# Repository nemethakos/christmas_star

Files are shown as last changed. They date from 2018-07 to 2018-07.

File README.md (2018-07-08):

# Christmas Star
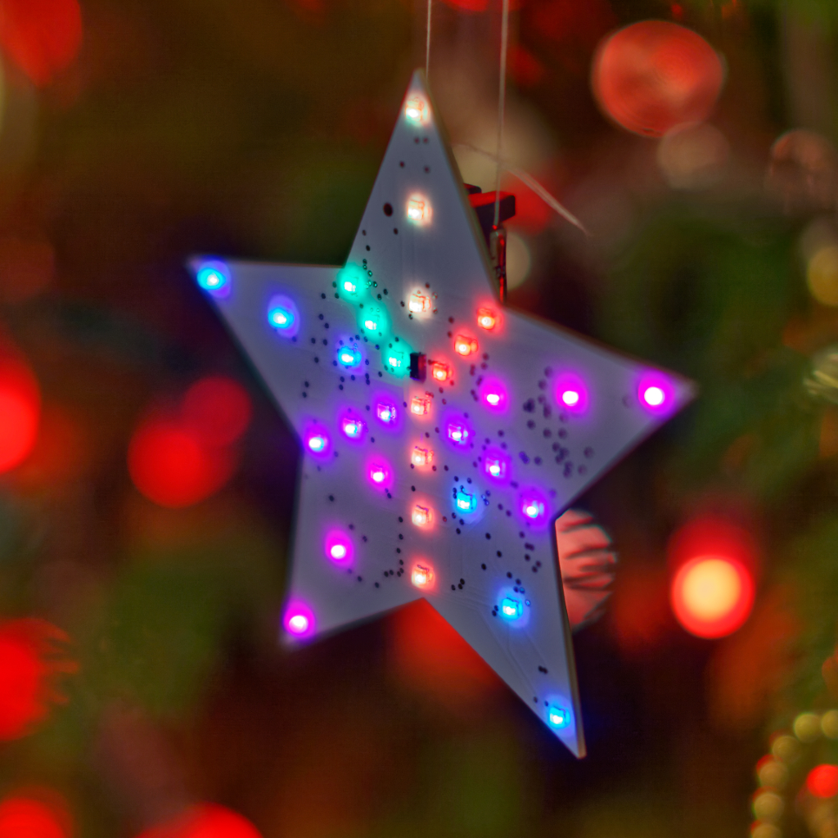
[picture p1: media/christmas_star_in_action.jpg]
Christmas Star in Action

Christmas Star is a Christmas ornament to be hanged onto a Christmas tree. 

It runs on a single AA Battery (Lithium, NiMh or Alkaline), has 31 APA102-2020 RGB LEDs driven by an ATMEGA 328P running on Arduino core. 
Gesture control by Avago APDS-9960 Gesture and Light sensor (sleep/wake up, next/previous effect).

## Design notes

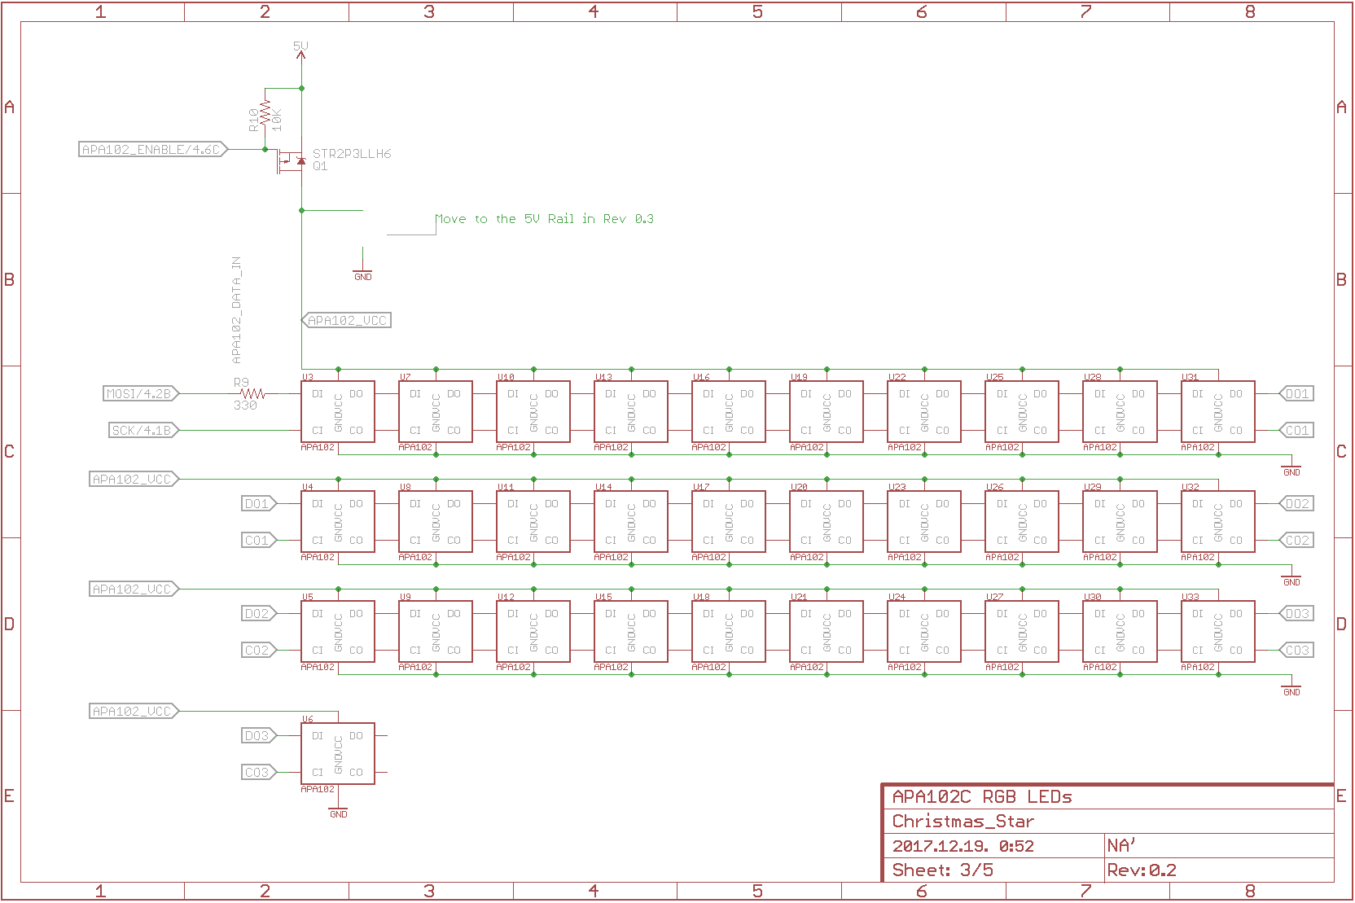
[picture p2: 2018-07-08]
media/sch3.png

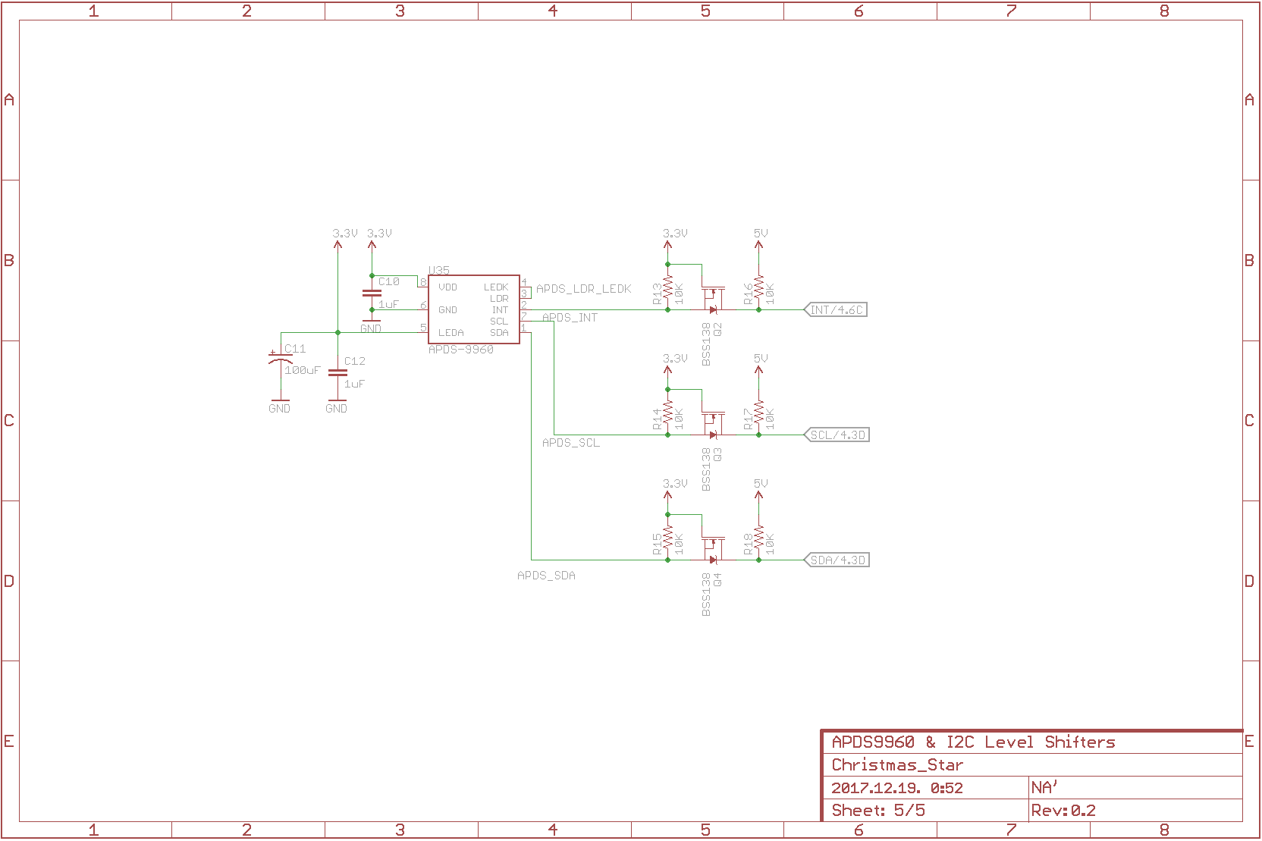
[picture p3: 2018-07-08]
media/sch5.png

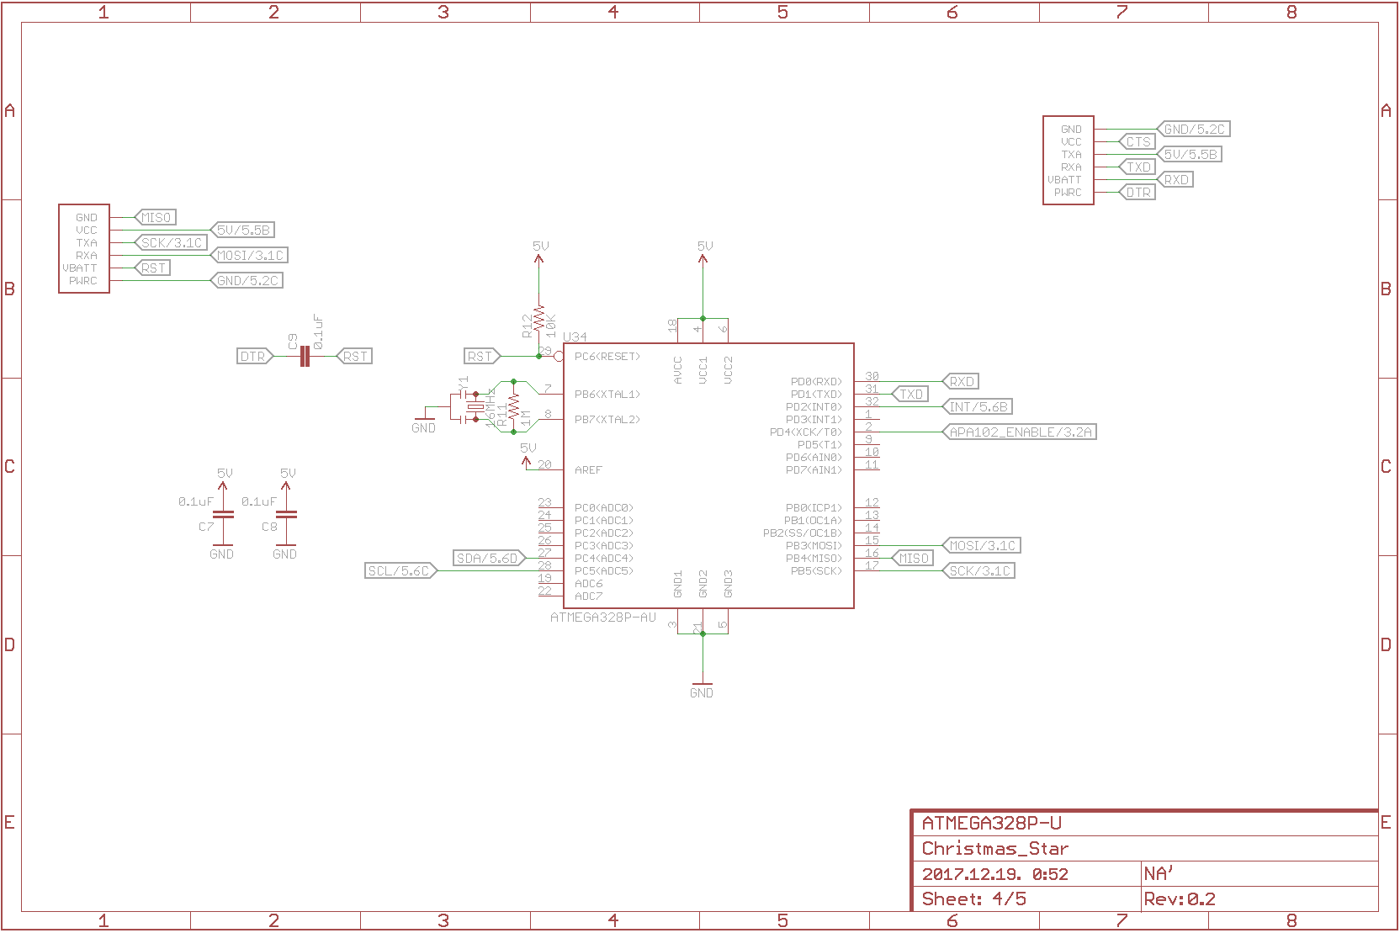
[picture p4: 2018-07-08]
media/sch4.png

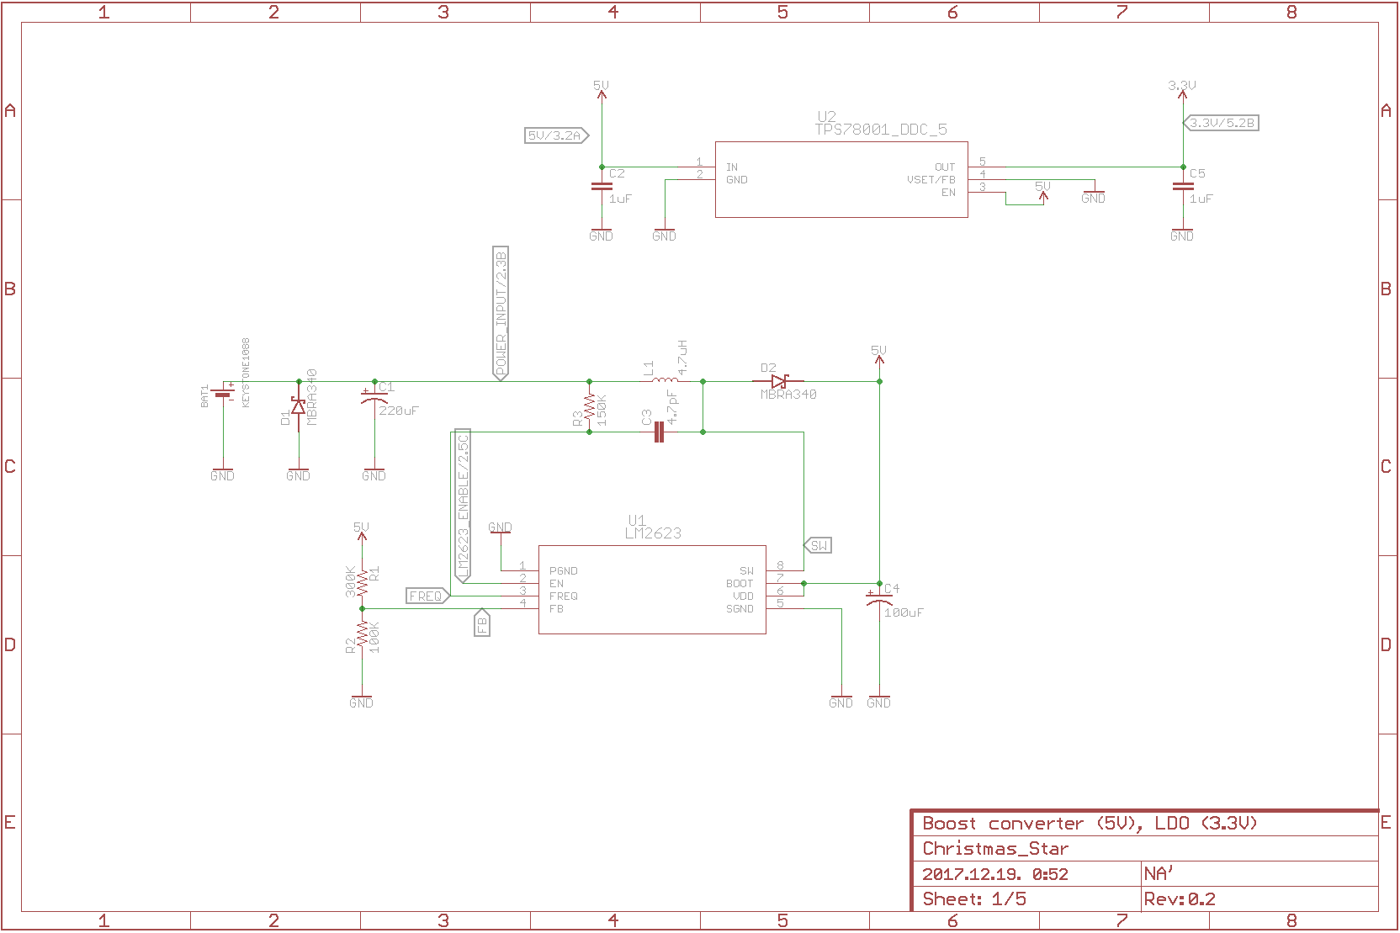
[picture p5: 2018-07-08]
media/sch1.png

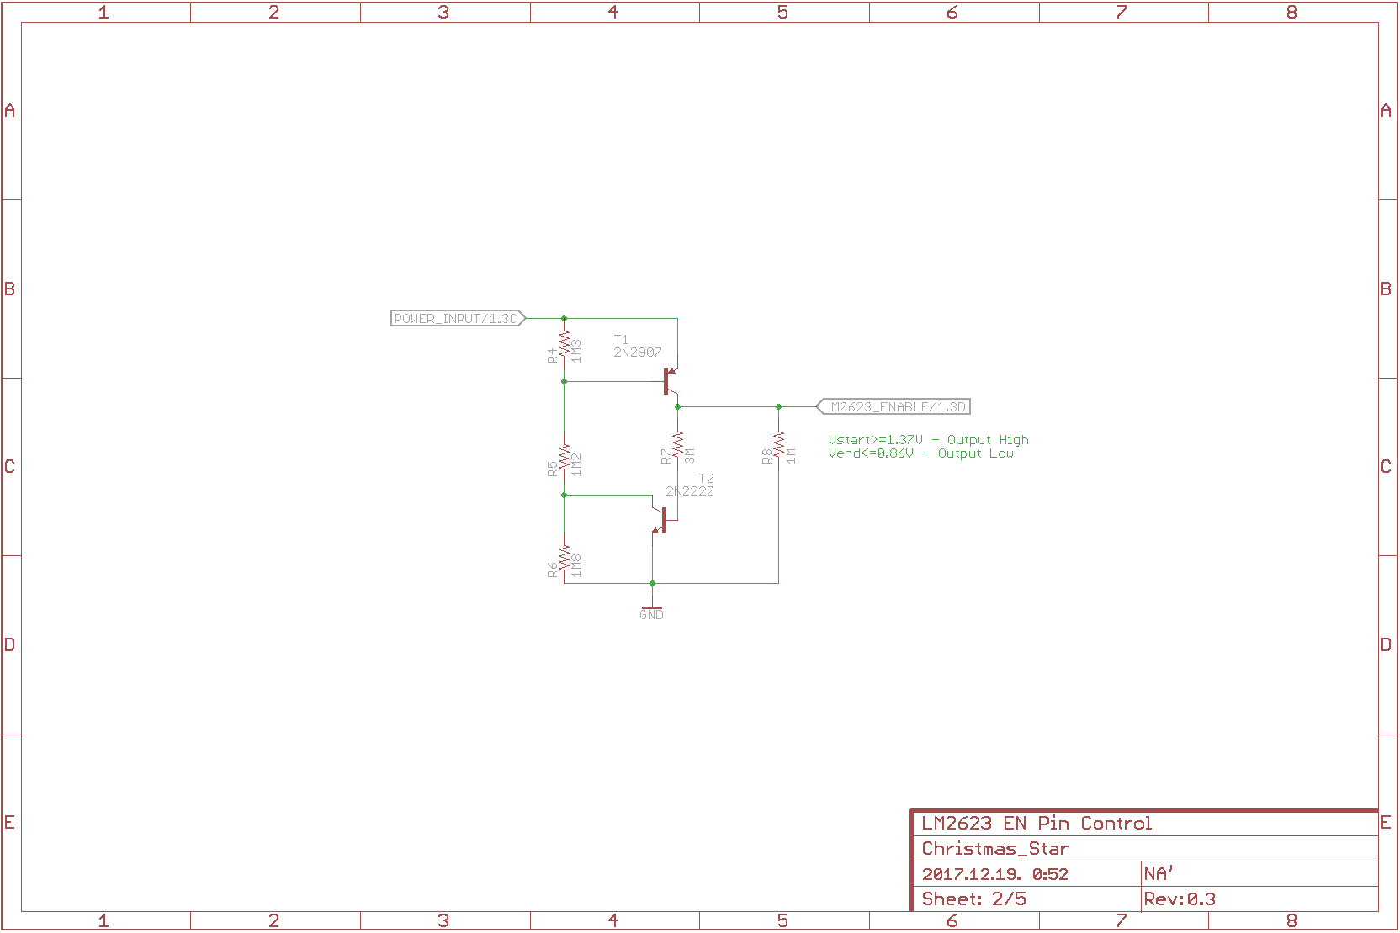
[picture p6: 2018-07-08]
media/sch2.png

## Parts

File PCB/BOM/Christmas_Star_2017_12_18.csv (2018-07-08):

Qty | Value | Device | Package | Parts | Description
3 | 0.1uF | CAP0603-CAP | 0603-CAP | C7, C8, C9 | Capacitor
1 | 1000uF | CPOL-USD/7343-31W | D/7343-31W | C6 | POLARIZED CAPACITOR, American symbol
1 | 100K | RESISTOR0603-RES | 0603-RES | R2 | Resistor
2 | 100uF | CAP_POL1206-KIT | EIA3216-KIT | C4, C11 | Capacitor Polarized
8 | 10K | RESISTOR0603-RES | 0603-RES | R10, R12, R13, R14, R15, R16, R17, R18 | Resistor
1 | 150K | RESISTOR0603-RES | 0603-RES | R3 | Resistor
1 | 16MHz | RESONATOR-16MHZSMD_3.2X1.3 | RESONATOR-SMD-3.2X1.3 | Y1 | 16MHz Resonator
2 | 1M | RESISTOR0603-RES | 0603-RES | R8, R11 | Resistor
1 | 1M2 | RESISTOR0603-RES | 0603-RES | R5 | Resistor
1 | 1M3 | RESISTOR0603-RES | 0603-RES | R4 | Resistor
1 | 1M8 | RESISTOR0603-RES | 0603-RES | R6 | Resistor
4 | 1uF | CAP0603-CAP | 0603-CAP | C2, C5, C10, C12 | Capacitor
1 | 220uF | CAP_POL3528-KIT | EIA3528-KIT | C1 | Capacitor Polarized
1 | 2N2222 | MMBT2222ALT1-NPN-SOT23-BEC | SOT23-BEC | T2 | NPN Transistror
1 | 2N2907 | MMBT2907ALT1-PNP-SOT23-BEC | SOT23-BEC | T1 | PNP Transistror
1 | 300K | RESISTOR0603-RES | 0603-RES | R1 | Resistor
1 | 330 | RESISTOR0603-RES | 0603-RES | R9 | Resistor
1 | 3M | RESISTOR0603-RES | 0603-RES | R7 | Resistor
1 | 4.7pF | CAP0603-CAP | 0603-CAP | C3 | Capacitor
1 | 4.7uH | INDUCTOR | LTF5022 | L1 | LTF5022 Footprint
31 | APA102 | APA1022020 | APA102_2020 | U3, U4, U5, U6, U7, U8, U9, U10, U11, U12, U13, U14, U15, U16, U17, U18, U19, U20, U21, U22, U23, U24, U25, U26, U27, U28, U29, U30, U31, U32, U33 | APA102C 5050 RGB LED
1 | APDS-9960 | APDS-9960 | APDS-9960 | U35 | Avago APDS-9960 Digital Proximity, Ambient Light, RGB, and Gesture Sensor.
1 | ATMEGA328P-AU | ATMEGA328P-AU | TQFP32 | U34 | Atmel 32-pin 8-bit microcontroller
3 | BSS138 | MOSFET-NCH-BSS138 | SOT23-3 | Q2, Q3, Q4 | N-channel MOSFETs
2 | GP-635TSMD | GP-635TSMD | GP-635T | ICSP, SERIAL | Footprint and symbol for a generic 6-pin JST GPS module connector.
1 | KEYSTONE1088 | KEYSTONE1088 | KEYSTONE1088 | BAT1
1 | LM2623_DGK_8 | LM2623_DGK_8 | MUA08A | U1
2 | MBRA340 | SS12 | DIOM4427X270N | D1, D2 | SS12 Series 500 mV 1 A 20 V Max Reverse Voltage Schottky Rectifier - DO-214AC
1 | STR2P3LLH6 | MOSFET_PCH-IRLML2244 | SOT23-3 | Q1 | P-channel MOSFETs
1 | TPS78001_DDC_5 | TPS78001_DDC_5 | DDC5 | U2

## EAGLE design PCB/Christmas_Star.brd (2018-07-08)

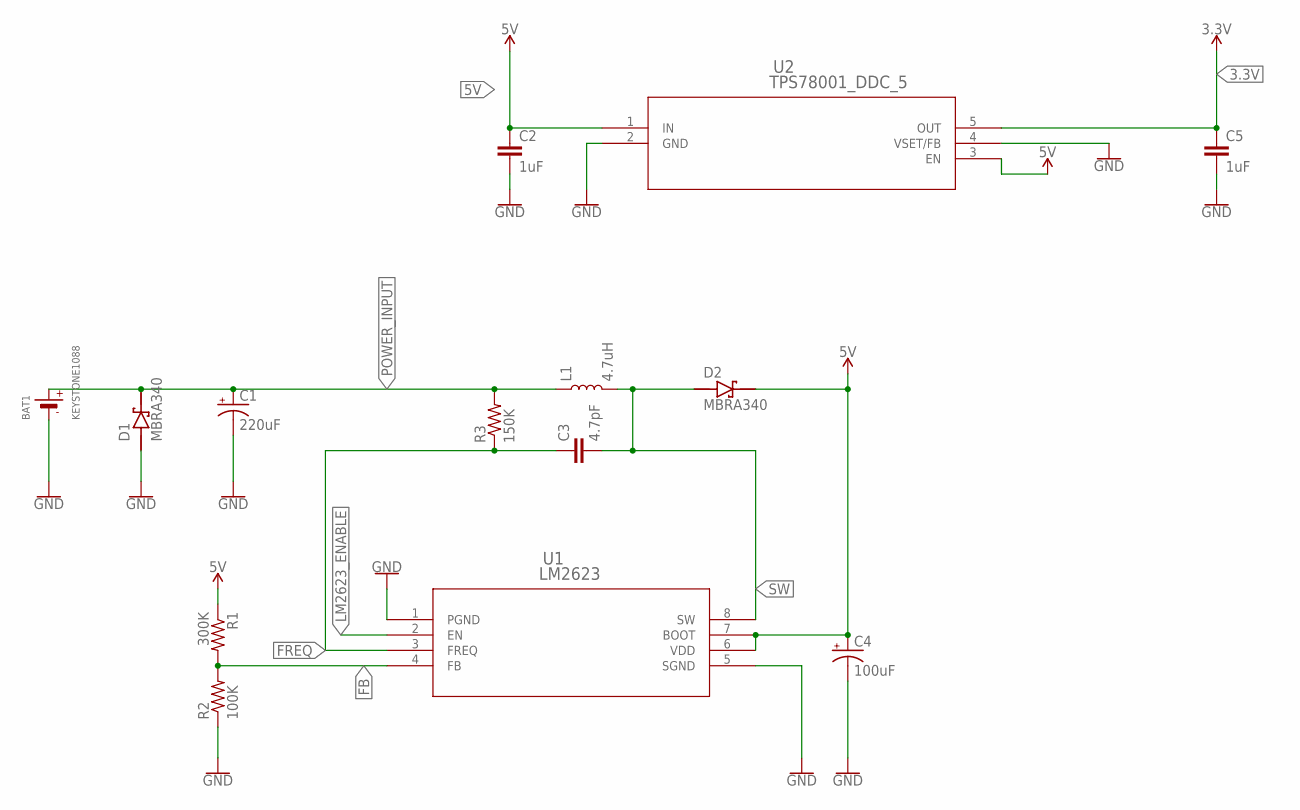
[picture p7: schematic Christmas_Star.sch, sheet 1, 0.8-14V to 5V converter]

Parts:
BAT1: KEYSTONE1088
C1: 220uF; EIA3528-KIT
C2, C5: 1uF; 0603-CAP
C3: 4.7pF; 0603-CAP
C4: 100uF; EIA3216-KIT
D1, D2: MBRA340; DIOM4427X270N
L1: 4.7uH; LTF5022
R1: 300K; 0603-RES
R2: 100K; 0603-RES
R3: 150K; 0603-RES
U1: LM2623; MUA08A
U2: TPS78001_DDC_5; DDC5

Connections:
3.3V: C5.1, U2.5 (OUT); also elsewhere on the board
5V: C2.1, C4.A (+), D2.C, R1.1, U1.6 (VDD), U1.7 (BOOT), U2.1 (IN), U2.3 (EN); also elsewhere on the board
FB: R1.2, R2.2, U1.4 (FB)
FREQ: C3.1, R3.1, U1.3 (FREQ)
GND: BAT1.-, C1.C (-), C2.2, C4.C (-), C5.2, D1.A, R2.1, U1.1 (PGND), U1.5 (SGND), U2.2 (GND), U2.4 (VSET/FB); also elsewhere on the board
LM2623_ENABLE: U1.2 (EN); also elsewhere on the board
POWER_INPUT: BAT1.+, C1.A (+), D1.C, L1.P$1 (1), R3.2; also elsewhere on the board
SW: C3.2, D2.A, L1.P$2 (2), U1.8 (SW)

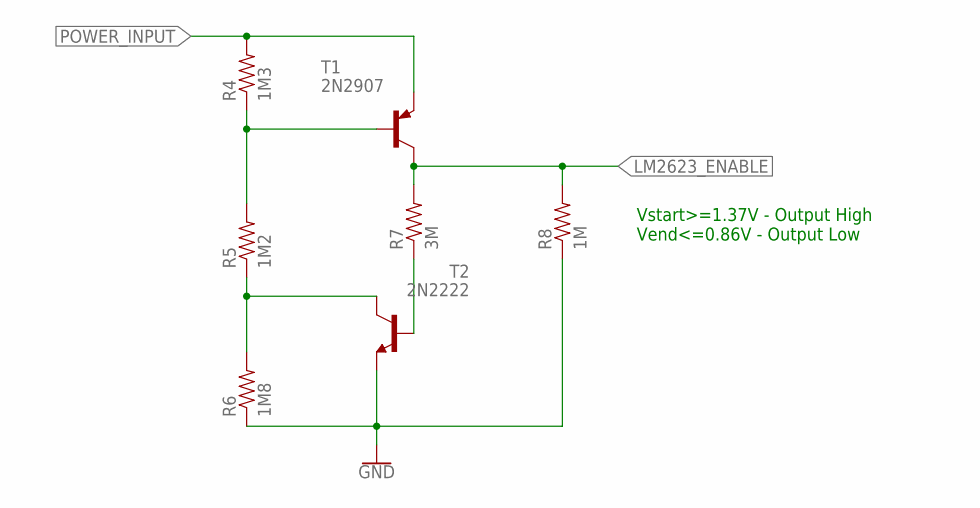
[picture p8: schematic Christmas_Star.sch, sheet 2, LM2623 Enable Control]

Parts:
R4: 1M3; 0603-RES
R5: 1M2; 0603-RES
R6: 1M8; 0603-RES
R7: 3M; 0603-RES
R8: 1M; 0603-RES
T1: 2N2907; SOT23-BEC
T2: 2N2222; SOT23-BEC

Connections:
GND: R6.1, R8.1, T2.E; also elsewhere on the board
LM2623_ENABLE: R7.2, R8.2, T1.C; also elsewhere on the board
unnamed: R4.1, R5.2, T1.B
unnamed: R5.1, R6.2, T2.C
unnamed: R7.1, T2.B
POWER_INPUT: R4.2, T1.E; also elsewhere on the board

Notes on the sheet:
Vstart>=1.37V - Output High Vend<=0.86V - Output Low

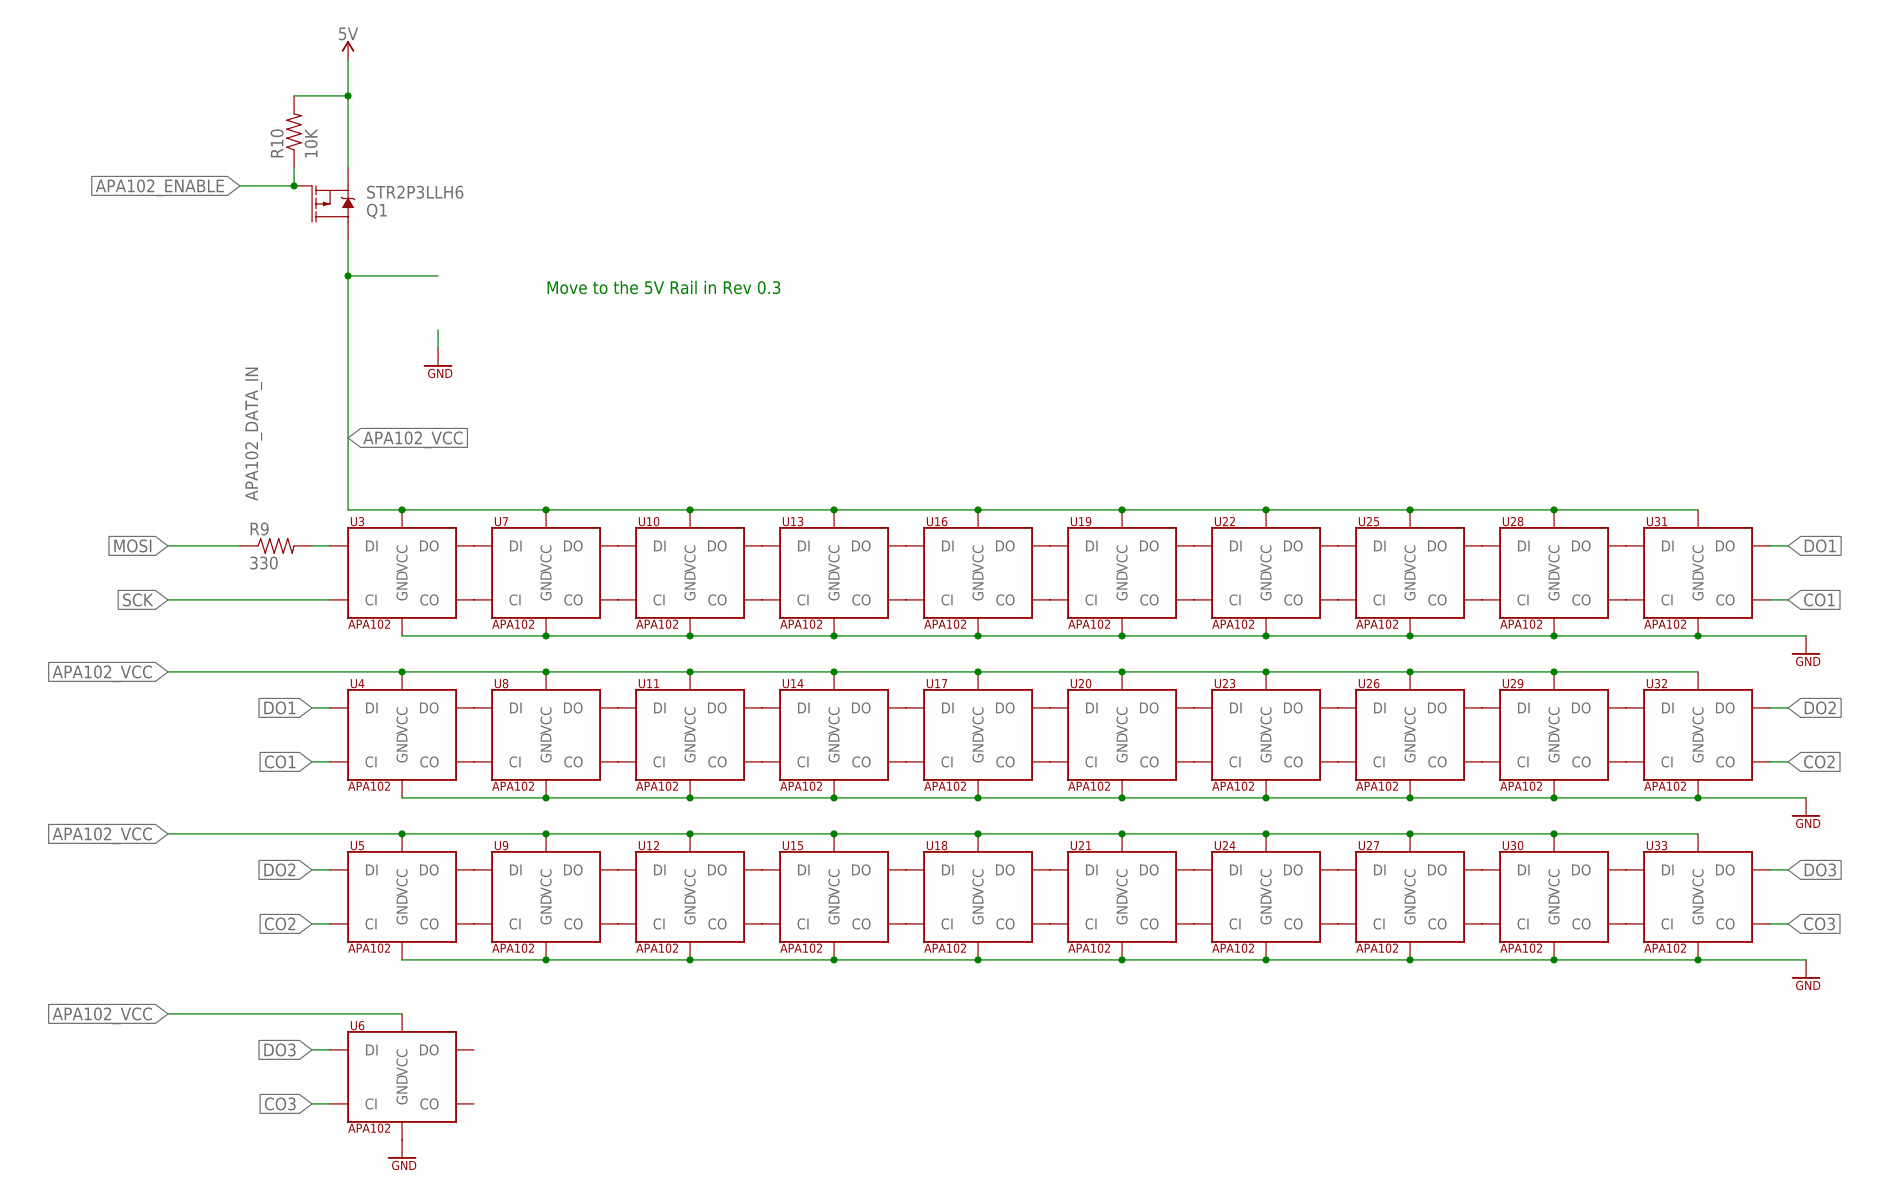
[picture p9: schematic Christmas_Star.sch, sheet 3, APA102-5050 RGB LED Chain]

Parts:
Q1: STR2P3LLH6; SOT23-3
R9: 330; 0603-RES
R10: 10K; 0603-RES
U3, U4, U5, U6, U7, U8, U9, U10, U11, U12, U13, U14, U15, U16, U17, U18, U19, U20, U21, U22, U23, U24, U25, U26, U27, U28, U29, U30, U31, U32, U33: APA102; APA102_2020

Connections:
5V: Q1.2 (S), R10.2; also elsewhere on the board
APA102_DATA_IN: R9.2, U3.D_IN (DI)
APA102_ENABLE: Q1.1 (G), R10.1; also elsewhere on the board
APA102_VCC: Q1.3 (D), U3.VCC, U4.VCC, U5.VCC, U6.VCC, U7.VCC, U8.VCC, U9.VCC, U10.VCC, U11.VCC, U12.VCC, U13.VCC, U14.VCC, U15.VCC, U16.VCC, U17.VCC, U18.VCC, U19.VCC, U20.VCC, U21.VCC, U22.VCC, U23.VCC, U24.VCC, U25.VCC, U26.VCC, U27.VCC, U28.VCC, U29.VCC, U30.VCC, U31.VCC, U32.VCC, U33.VCC
CO1: U4.C_IN (CI), U31.CL_OUT (CO)
CO2: U5.C_IN (CI), U32.CL_OUT (CO)
CO3: U6.C_IN (CI), U33.CL_OUT (CO)
DO1: U4.D_IN (DI), U31.D_OUT (DO)
DO2: U5.D_IN (DI), U32.D_OUT (DO)
DO3: U6.D_IN (DI), U33.D_OUT (DO)
GND: U3.GND, U4.GND, U5.GND, U6.GND, U7.GND, U8.GND, U9.GND, U10.GND, U11.GND, U12.GND, U13.GND, U14.GND, U15.GND, U16.GND, U17.GND, U18.GND, U19.GND, U20.GND, U21.GND, U22.GND, U23.GND, U24.GND, U25.GND, U26.GND, U27.GND, U28.GND, U29.GND, U30.GND, U31.GND, U32.GND, U33.GND; also elsewhere on the board
MOSI: R9.1; also elsewhere on the board
unnamed: U3.D_OUT (DO), U7.D_IN (DI)
unnamed: U3.CL_OUT (CO), U7.C_IN (CI)
unnamed: U7.D_OUT (DO), U10.D_IN (DI)
unnamed: U7.CL_OUT (CO), U10.C_IN (CI)
unnamed: U10.D_OUT (DO), U13.D_IN (DI)
unnamed: U10.CL_OUT (CO), U13.C_IN (CI)
unnamed: U13.D_OUT (DO), U16.D_IN (DI)
unnamed: U13.CL_OUT (CO), U16.C_IN (CI)
unnamed: U16.D_OUT (DO), U19.D_IN (DI)
unnamed: U16.CL_OUT (CO), U19.C_IN (CI)
unnamed: U19.D_OUT (DO), U22.D_IN (DI)
unnamed: U19.CL_OUT (CO), U22.C_IN (CI)
unnamed: U22.D_OUT (DO), U25.D_IN (DI)
unnamed: U22.CL_OUT (CO), U25.C_IN (CI)
unnamed: U25.D_OUT (DO), U28.D_IN (DI)
unnamed: U25.CL_OUT (CO), U28.C_IN (CI)
unnamed: U28.D_OUT (DO), U31.D_IN (DI)
unnamed: U28.CL_OUT (CO), U31.C_IN (CI)
unnamed: U4.D_OUT (DO), U8.D_IN (DI)
unnamed: U4.CL_OUT (CO), U8.C_IN (CI)
unnamed: U8.D_OUT (DO), U11.D_IN (DI)
unnamed: U8.CL_OUT (CO), U11.C_IN (CI)
unnamed: U11.D_OUT (DO), U14.D_IN (DI)
unnamed: U11.CL_OUT (CO), U14.C_IN (CI)
unnamed: U14.D_OUT (DO), U17.D_IN (DI)
unnamed: U14.CL_OUT (CO), U17.C_IN (CI)
unnamed: U17.D_OUT (DO), U20.D_IN (DI)
unnamed: U17.CL_OUT (CO), U20.C_IN (CI)
unnamed: U20.D_OUT (DO), U23.D_IN (DI)
unnamed: U20.CL_OUT (CO), U23.C_IN (CI)
unnamed: U23.D_OUT (DO), U26.D_IN (DI)
unnamed: U23.CL_OUT (CO), U26.C_IN (CI)
unnamed: U26.D_OUT (DO), U29.D_IN (DI)
unnamed: U26.CL_OUT (CO), U29.C_IN (CI)
unnamed: U29.D_OUT (DO), U32.D_IN (DI)
unnamed: U29.CL_OUT (CO), U32.C_IN (CI)
unnamed: U5.D_OUT (DO), U9.D_IN (DI)
unnamed: U5.CL_OUT (CO), U9.C_IN (CI)
unnamed: U9.D_OUT (DO), U12.D_IN (DI)
unnamed: U9.CL_OUT (CO), U12.C_IN (CI)
unnamed: U12.D_OUT (DO), U15.D_IN (DI)
unnamed: U12.CL_OUT (CO), U15.C_IN (CI)
unnamed: U15.D_OUT (DO), U18.D_IN (DI)
unnamed: U15.CL_OUT (CO), U18.C_IN (CI)
unnamed: U18.D_OUT (DO), U21.D_IN (DI)
unnamed: U18.CL_OUT (CO), U21.C_IN (CI)
unnamed: U21.D_OUT (DO), U24.D_IN (DI)
unnamed: U21.CL_OUT (CO), U24.C_IN (CI)
unnamed: U24.D_OUT (DO), U27.D_IN (DI)
unnamed: U24.CL_OUT (CO), U27.C_IN (CI)
unnamed: U27.D_OUT (DO), U30.D_IN (DI)
unnamed: U27.CL_OUT (CO), U30.C_IN (CI)
unnamed: U30.D_OUT (DO), U33.D_IN (DI)
unnamed: U30.CL_OUT (CO), U33.C_IN (CI)
SCK: U3.C_IN (CI); also elsewhere on the board

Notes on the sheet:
Move to the 5V Rail in Rev 0.3

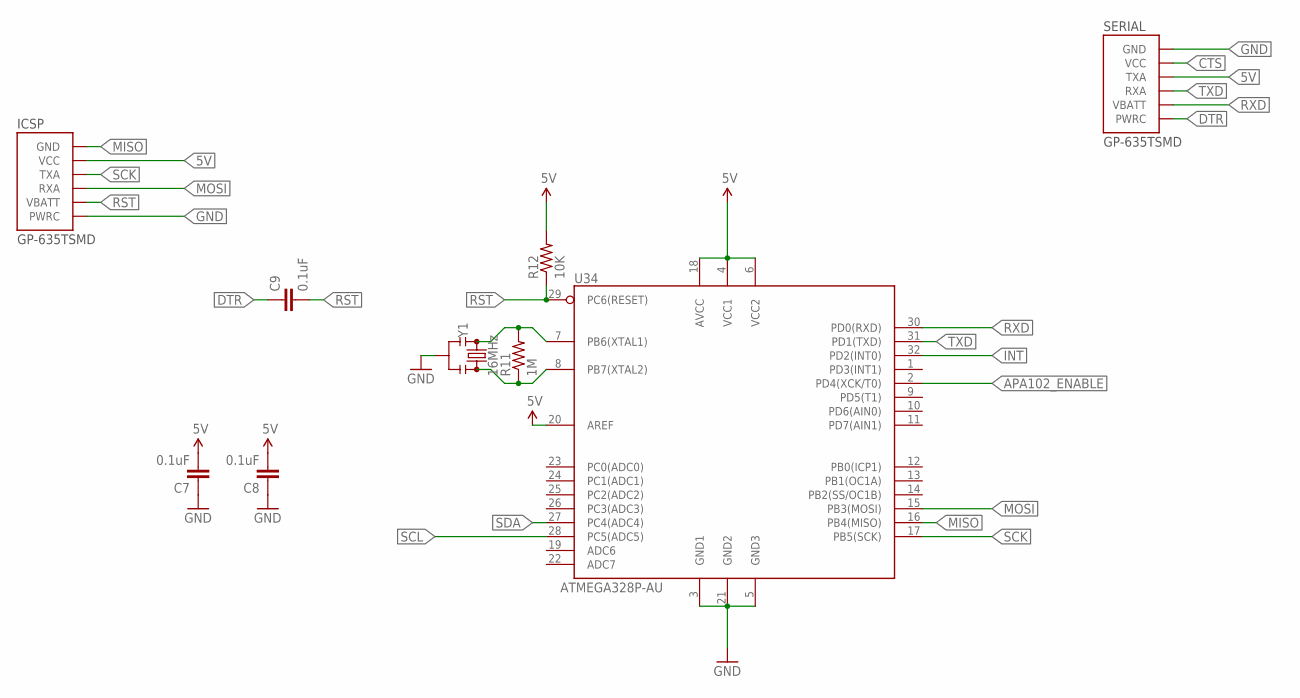
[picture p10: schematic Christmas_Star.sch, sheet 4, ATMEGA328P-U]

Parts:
C7, C8, C9: 0.1uF; 0603-CAP
ICSP: GP-635TSMD; GP-635T
R11: 1M; 0603-RES
R12: 10K; 0603-RES
SERIAL: GP-635TSMD; GP-635T
U34: ATMEGA328P-AU; TQFP32
Y1: 16MHz; RESONATOR-SMD-3.2X1.3

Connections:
5V: C7.2, C8.2, ICSP.2 (VCC), R12.2, SERIAL.3 (TXA), U34.4 (VCC1), U34.6 (VCC2), U34.18 (AVCC), U34.20 (AREF); also elsewhere on the board
APA102_ENABLE: U34.2 (PD4(XCK/T0)); also elsewhere on the board
CTS: SERIAL.2 (VCC)
DTR: C9.1, SERIAL.6 (PWRC)
GND: C7.1, C8.1, ICSP.6 (PWRC), SERIAL.1 (GND), U34.3 (GND1), U34.5 (GND3), U34.21 (GND2), Y1.2; also elsewhere on the board
INT: U34.32 (PD2(INT0)); also elsewhere on the board
MISO: ICSP.1 (GND), U34.16 (PB4(MISO))
MOSI: ICSP.4 (RXA), U34.15 (PB3(MOSI)); also elsewhere on the board
unnamed: R11.2, U34.7 (PB6(XTAL1)), Y1.1
unnamed: R11.1, U34.8 (PB7(XTAL2)), Y1.3
RST: C9.2, ICSP.5 (VBATT), R12.1, U34.29 (PC6(RESET))
RXD: SERIAL.5 (VBATT), U34.30 (PD0(RXD))
SCK: ICSP.3 (TXA), U34.17 (PB5(SCK)); also elsewhere on the board
SCL: U34.28 (PC5(ADC5)); also elsewhere on the board
SDA: U34.27 (PC4(ADC4)); also elsewhere on the board
TXD: SERIAL.4 (RXA), U34.31 (PD1(TXD))

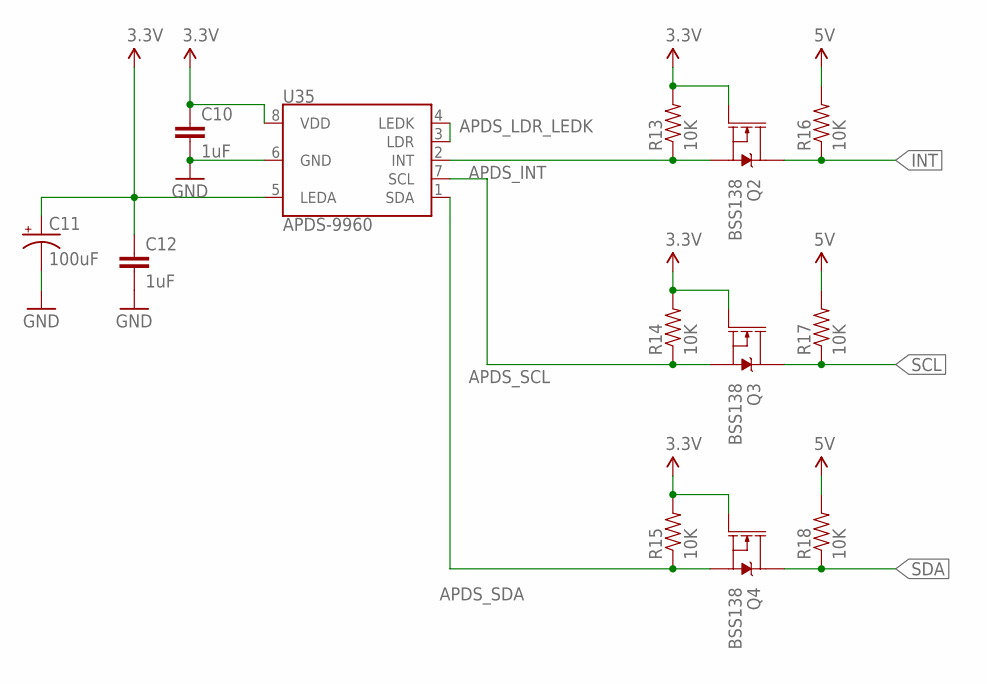
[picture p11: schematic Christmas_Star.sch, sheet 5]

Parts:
C10, C12: 1uF; 0603-CAP
C11: 100uF; EIA3216-KIT
Q2, Q3, Q4: BSS138; SOT23-3
R13, R14, R15, R16, R17, R18: 10K; 0603-RES
U35: APDS-9960

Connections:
3.3V: C10.1, C11.A (+), C12.1, Q2.1 (G), Q3.1 (G), Q4.1 (G), R13.2, R14.2, R15.2, U35.5 (LEDA), U35.8 (VDD); also elsewhere on the board
5V: R16.2, R17.2, R18.2; also elsewhere on the board
APDS_INT: Q2.2 (S), R13.1, U35.2 (INT)
APDS_LDR_LEDK: U35.3 (LDR), U35.4 (LEDK)
APDS_SCL: Q3.2 (S), R14.1, U35.7 (SCL)
APDS_SDA: Q4.2 (S), R15.1, U35.1 (SDA)
GND: C10.2, C11.C (-), C12.2, U35.6 (GND); also elsewhere on the board
INT: Q2.3 (D), R16.1; also elsewhere on the board
SCL: Q3.3 (D), R17.1; also elsewhere on the board
SDA: Q4.3 (D), R18.1; also elsewhere on the board

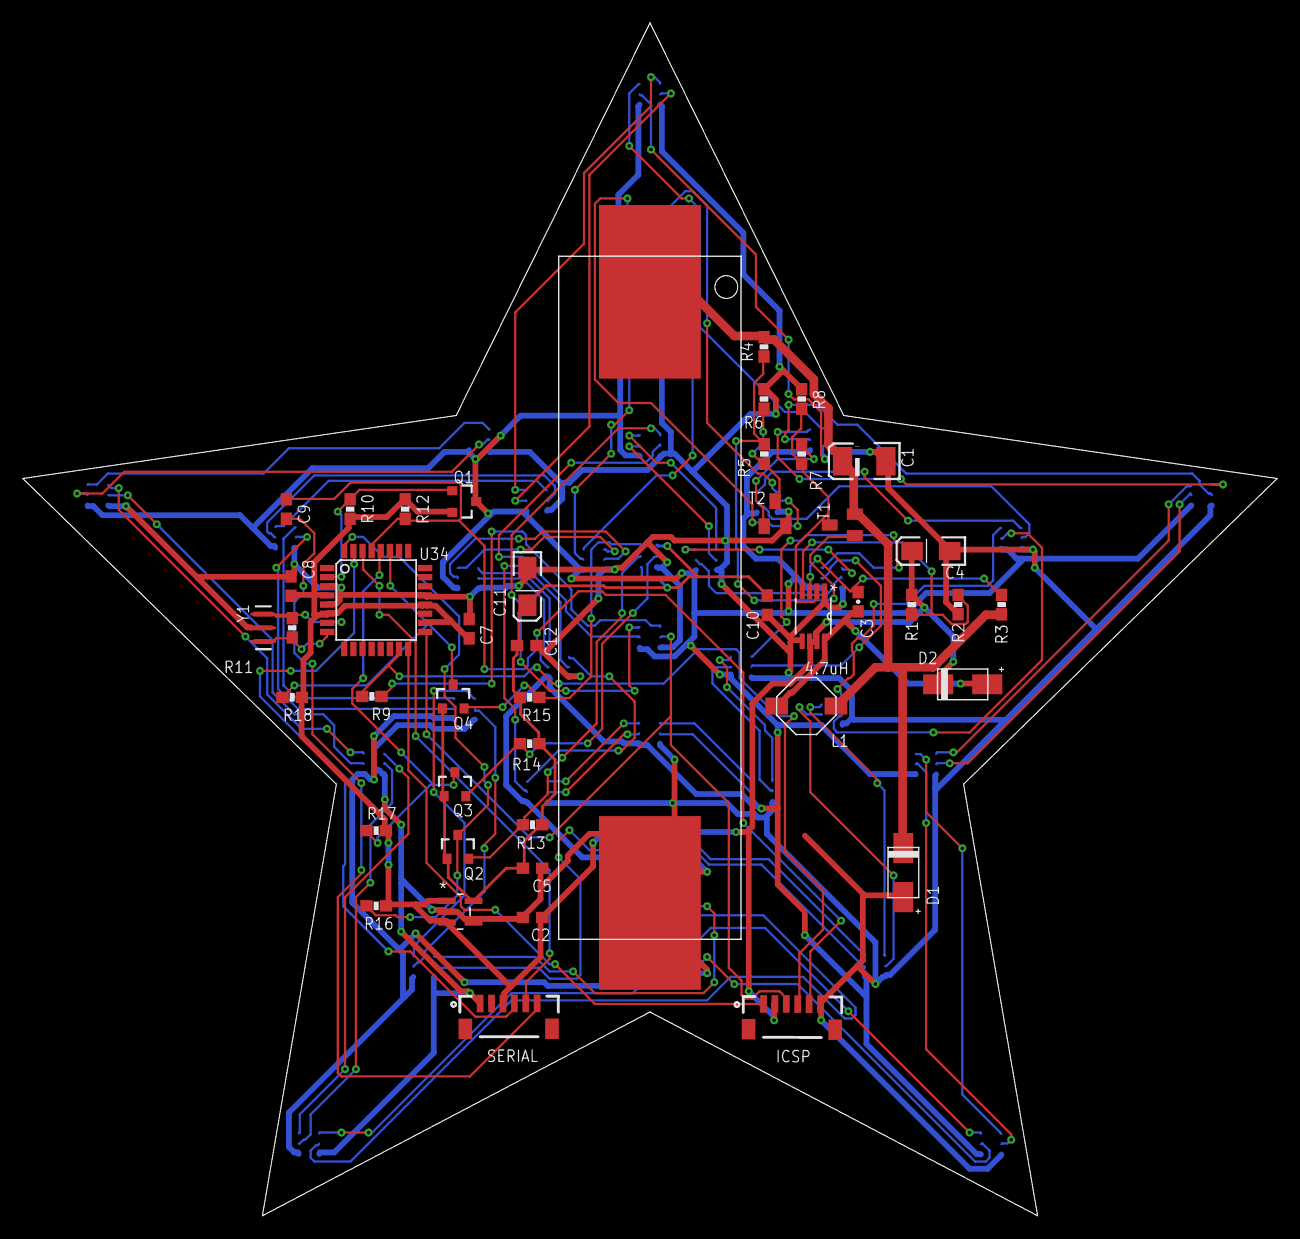
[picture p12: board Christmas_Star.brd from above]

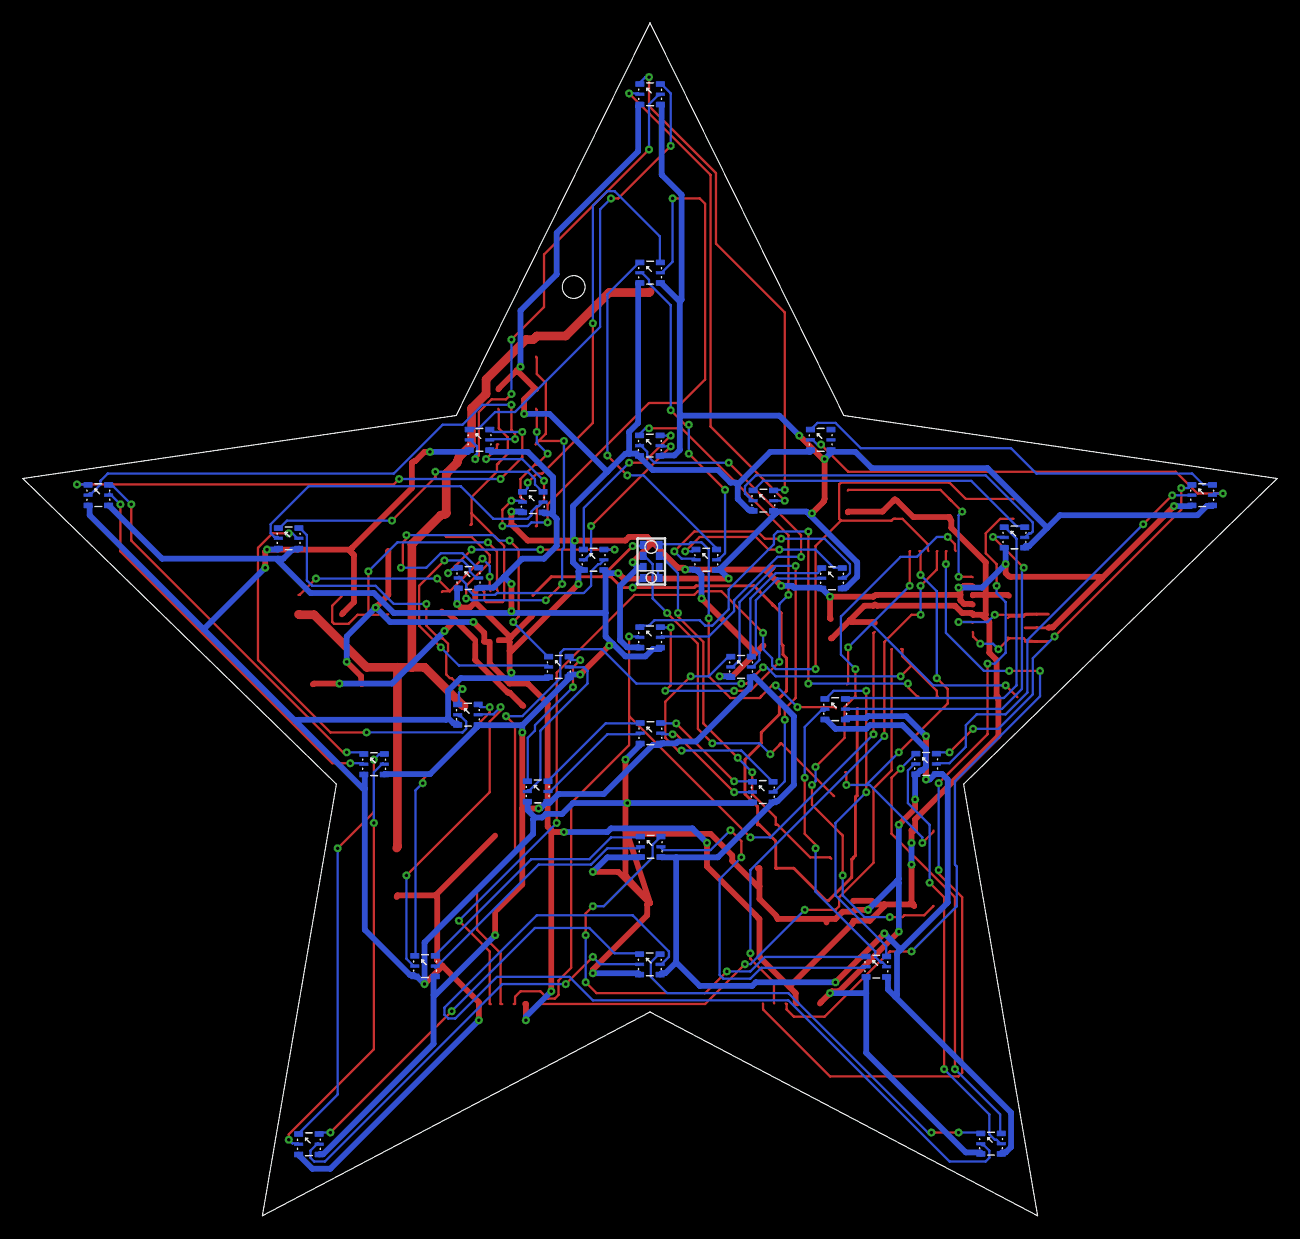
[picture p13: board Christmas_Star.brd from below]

Board: 2 copper layers, 110.0 x 104.6 mm, 77 parts (32 on the bottom side), 90 nets.

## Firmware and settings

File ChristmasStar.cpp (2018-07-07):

#include "ChristmasStar.h"
#include <avr/sleep.h>
#include <avr/interrupt.h>
#include <avr/power.h>
#include <SparkFun_APDS9960.h>

#include "EffectPlayer.h"
#include <LowPower.h>
#include <avr/pgmspace.h>

#define MAX_BRIGHTNESS (20)
#define INITIAL_BRIGHTNESS (10)
#define MIN_BRIGHTNESS (5)
#define NO_GESTURE_TIME (1000)

struct LIGHTDATA {
	uint16_t red;
	uint16_t green;
	uint16_t blue;
	uint16_t ambient;
};

uint8_t brightness;

uint16_t frame = 0;

EffectPlayer player = EffectPlayer(ledBuffer);

SparkFun_APDS9960 apds = SparkFun_APDS9960();

bool interruptReceived = 0;

CRGB saveBuffer[NUMBER_OF_LEDS];

void drawRadii(uint8_t startIndex, bool drawCenter, CRGB color) {
	if (startIndex <= 10) {
		if (drawCenter) {
			ledBuffer[0] = color;
		}
		for (uint8_t i = startIndex; i <= 30; i += 10) {
			ledBuffer[i] = color;
		}
	}
}

enum ARROW {
	NONE, UP, DOWN, LEFT, RIGHT
};

ARROW arrowOverlay;
unsigned long displayArrowUntil;

void drawCenterArrow(uint8_t startIndex1, uint8_t startIndex2,
		uint8_t startIndex3, CRGB color) {
	drawRadii(startIndex1, true, color);
	drawRadii(startIndex2, false, color);
	drawRadii(startIndex3, false, color);
}

void drawArrow(ARROW arrow, CRGB color) {
	switch (arrow) {
	case UP:
		drawCenterArrow(4, 6, 8, color);
		break;
	case DOWN:
		drawCenterArrow(1, 2, 10, color);
		break;
	case LEFT:
		drawCenterArrow(2, 3, 4, color);
		break;
	case RIGHT:
		drawCenterArrow(8, 9, 10, color);
		break;
	case NONE:
		break;
	}
}

void resetAPDSInterrupt() {
	interruptReceived = false;
}

void receiveAPDSInterrupt() {
	interruptReceived = true;
}

void updateBrightness() {
	FastLED.setBrightness(brightness);
}

void increaseBrightness() {
	/*	if (brightness < MAX_BRIGHTNESS) {
	 brightness++;
	 }
	 updateBrightness();*/
}

volatile int proximitInterruptValue;

void sleepInterrupt() {
	noInterrupts();
	detachInterrupt(0);

	proximitInterruptValue++;

	interrupts();
}

bool enableProximitySensorInt(uint8_t pgain, uint8_t ldrive,
		uint8_t nearTreshold, uint8_t farTreshold) {
	/* Set default gain, LED, interrupts, enable power, and enable sensor */
	if (!apds.setProximityGain(pgain)) {
		return false;
	}
	if (!apds.setLEDDrive(ldrive)) {
		return false;
	}

	if (!apds.setProximityIntHighThreshold(farTreshold)) {
		return false;
	}

	if (!apds.setProximityIntLowThreshold(nearTreshold)) {
		return false;
	}

	if (!apds.setProximityIntEnable(1)) {
		return false;
	}

	if (!apds.enablePower()) {
		return false;
	}
	if (!apds.setMode(PROXIMITY, 1)) {
		return false;
	}

	return true;
}
#pragma GCC push_options
#pragma GCC optimize ("O0")
void emptyGestureQueue() {

	while (apds.isGestureAvailable()) {
		int gesture = apds.readGesture();

	}

}
#pragma GCC pop_options

void enterSleepMode() {
	// disable APA102
	pinMode(APA102_ENABLE_PIN, INPUT);
	digitalWrite(APA102_ENABLE_PIN, HIGH);

	//Serial.println("Sleep...");

	detachInterrupt(0);

	apds.init();
	//emptyGestureQueue();
	enableProximitySensorInt(0, 3, 0, 10);
	apds.clearProximityInt();
	attachInterrupt(0, sleepInterrupt, LOW);

	LowPower.powerDown(SLEEP_FOREVER, ADC_OFF, BOD_ON);
	detachInterrupt(0);
	setup();
}

void displayArrow(ARROW arrow, unsigned long displayTimeMS) {
	arrowOverlay = arrow;
	displayArrowUntil = millis() + displayTimeMS;
}
unsigned long noGestureUntilMs = 0;

void printGesture(int gesture) {
	switch (gesture) {
				case DIR_UP:
					Serial.println(F("UP"));
					break;
				case DIR_DOWN:
					Serial.println(F("DOWN"));
					break;
				case DIR_LEFT:
					Serial.println(F("LEFT"));
					break;
				case DIR_RIGHT:
					Serial.println(F("RIGHT"));
					break;
				case DIR_NEAR:
					Serial.println(F("NEAR"));
					break;
				case DIR_FAR:
					Serial.println(F("FAR"));
					break;
				default:
					Serial.println(F("NONE"));
					break;
				}
}

bool handleGesture() {
	//Serial.println("Handle Gesture");
	if (apds.isGestureAvailable()) {

		//Serial.println("Gesture available...");

		int gesture = apds.readGesture();
		//printGesture(gesture);
		bool processGesture = noGestureUntilMs < millis();
		//Serial.print("Process gesture: ");
		//Serial.println(processGesture);

		if (processGesture) {
			switch (gesture) {
			case DIR_UP:
				displayArrow(UP, 1000);
//				increaseBrightness();
				break;
			case DIR_DOWN:
				enterSleepMode();
				break;
			case DIR_LEFT:
				noGestureUntilMs = millis() + NO_GESTURE_TIME;
				displayArrow(RIGHT, 1000);
				player.prevEffect();
				break;
			case DIR_RIGHT:
				noGestureUntilMs = millis() + NO_GESTURE_TIME;
				displayArrow(LEFT, 1000);
				player.nextEffect();
				break;
			case DIR_NEAR:
				break;
			case DIR_FAR:
				break;
			default:
				break;
			}
		}
		return true;
	} else {
		//Serial.println("No gesture available");
	}
	return false;
}
void attachAPDSInterrupt() {
	attachInterrupt(APDS_INTERRUPT, receiveAPDSInterrupt, FALLING);
}

void detachAPDSInterrupt() {
	detachInterrupt(APDS_INTERRUPT);
}

void setup() {

	brightness = INITIAL_BRIGHTNESS;

	pinMode(APA102_ENABLE_PIN, OUTPUT);
	digitalWrite(APA102_ENABLE_PIN, LOW);

	FastLED.addLeds<APA102, BGR>(ledBuffer, NUMBER_OF_LEDS);
	//FastLED.setMaxPowerInVoltsAndMilliamps(5, 100);
	updateBrightness();
	//setDots(CRGB::Black);
	//Serial.begin(115200);
	if (apds.init()) {
		//Serial.println(F("APDS OK"));
		//emptyGestureQueue();
		apds.enableGestureSensor(true);
		apds.setLEDDrive(3);
		apds.clearProximityInt();
		attachAPDSInterrupt();
		noGestureUntilMs = millis() + NO_GESTURE_TIME;
	}

	//Serial.println(F("Setup finished..."));
}

/**
 * Check if Light reading is available
 */
void handleLight() {
	LIGHTDATA light;

	// Read the light levels (ambient, red, green, blue)
	if (!apds.readAmbientLight(light.ambient) || !apds.readRedLight(light.red)
			|| !apds.readGreenLight(light.green)
			|| !apds.readBlueLight(light.blue)) {
		//	Serial.println(F("Error reading light values"));
	} else {
		/*		Serial.print(F("Ambient: "));
		 Serial.print(light.ambient);
		 Serial.print(F(" Red: "));
		 Serial.print(light.red);
		 Serial.print(F(" Green: "));
		 Serial.print(light.green);
		 Serial.print(F(" Blue: "));
		 Serial.println(light.blue);*/
	}
}

void handleAPDS() {
	if (interruptReceived) {
		detachAPDSInterrupt();
//		Serial.println(F("APDS INT"));
//		handleLight();
		handleGesture();

		resetAPDSInterrupt();
		attachAPDSInterrupt();
	}
}

void darken(CRGB color) {
	for (int i = 0; i < NUMBER_OF_LEDS; i++) {
		ledBuffer[i] -= color;
	}
}

CRGB darkColor(50, 50, 50);

void drawOverlay() {
	if (arrowOverlay != NONE && millis() < displayArrowUntil) {
		//memcpy(saveBuffer, ledBuffer, sizeof(saveBuffer));
		darken(darkColor);
		drawArrow(arrowOverlay, CRGB::White);
		FastLED.show();
		//memcpy(ledBuffer, saveBuffer, sizeof(ledBuffer));
	} else {
		FastLED.show();
	}
}

void loop() {
	player.updateEffect();
	drawOverlay();
	handleAPDS();
}

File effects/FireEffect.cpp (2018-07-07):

#include "FireEffect.h"
// Fire2012 by Mark Kriegsman, July 2012
// as part of "Five Elements" shown here: http://youtu.be/knWiGsmgycY
////
// This basic one-dimensional 'fire' simulation works roughly as follows:
// There's a underlying array of 'heat' cells, that model the temperature
// at each point along the line.  Every cycle through the simulation,
// four steps are performed:
//  1) All cells cool down a little bit, losing heat to the air
//  2) The heat from each cell drifts 'up' and diffuses a little
//  3) Sometimes randomly new 'sparks' of heat are added at the bottom
//  4) The heat from each cell is rendered as a color into the leds array
//     The heat-to-color mapping uses a black-body radiation approximation.
//
// Temperature is in arbitrary units from 0 (cold black) to 255 (white hot).
//
// This simulation scales it self a bit depending on NUM_LEDS; it should look
// "OK" on anywhere from 20 to 100 LEDs without too much tweaking.
//
// I recommend running this simulation at anywhere from 30-100 frames per second,
// meaning an interframe delay of about 10-35 milliseconds.
//
// Looks best on a high-density LED setup (60+ pixels/meter).
//
//
// There are two main parameters you can play with to control the look and
// feel of your fire: COOLING (used in step 1 above), and SPARKING (used
// in step 3 above).
//
// COOLING: How much does the air cool as it rises?
// Less cooling = taller flames.  More cooling = shorter flames.
// Default 55, suggested range 20-100
#define COOLING  200

// SPARKING: What chance (out of 255) is there that a new spark will be lit?
// Higher chance = more roaring fire.  Lower chance = more flickery fire.
// Default 120, suggested range 50-200.
#define SPARKING 150
#define BRIGHTNESS  200

#define CELL_NUM (HEAT_ROW_NUM * HEAT_COL_NUM)

FireEffect::FireEffect() {
}

void FireEffect::initEffect(CRGB rawLEDBuffer[]) {
	frame = 0;
	ledBuffer = rawLEDBuffer;
	// This first palette is the basic 'black body radiation' colors,
	// which run from black to red to bright yellow to white.
	gPal = HeatColors_p;

	// These are other ways to set up the color palette for the 'fire'.
	// First, a gradient from black to red to yellow to white -- similar to HeatColors_p
	//   gPal = CRGBPalette16( CRGB::Black, CRGB::Red, CRGB::Yellow, CRGB::White);

	// Second, this palette is like the heat colors, but blue/aqua instead of red/yellow
	//   gPal = CRGBPalette16( CRGB::Black, CRGB::Blue, CRGB::Aqua,  CRGB::White);

	// Third, here's a simpler, three-step gradient, from black to red to white
	//   gPal = CRGBPalette16( CRGB::Black, CRGB::Red, CRGB::White);
	for (int row = 0; row < HEAT_ROW_NUM; row++) {
		for (int col = 0; col < HEAT_COL_NUM; col++) {
			heat[row][col] = 0;
		}
	}
}

// Fire2012 with programmable Color Palette
//
// This code is the same fire simulation as the original "Fire2012",
// but each heat cell's temperature is translated to color through a FastLED
// programmable color palette, instead of through the "HeatColor(...)" function.
//
// Four different static color palettes are provided here, plus one dynamic one.
//
// The three static ones are:
//   1. the FastLED built-in HeatColors_p -- this is the default, and it looks
//      pretty much exactly like the original Fire2012.
//
//  To use any of the other palettes below, just "uncomment" the corresponding code.
//
//   2. a gradient from black to red to yellow to white, which is
//      visually similar to the HeatColors_p, and helps to illustrate
//      what the 'heat colors' palette is actually doing,
//   3. a similar gradient, but in blue colors rather than red ones,
//      i.e. from black to blue to aqua to white, which results in
//      an "icy blue" fire effect,
//   4. a simplified three-step gradient, from black to red to white, just to show
//      that these gradients need not have four components; two or
//      three are possible, too, even if they don't look quite as nice for fire.
//
// The dynamic palette shows how you can change the basic 'hue' of the
// color palette every time through the loop, producing "rainbow fire".

void FireEffect::updateEffect() {

	// Add entropy to random number generator; we use a lot of it.
	random16_add_entropy(random());

	// Fourth, the most sophisticated: this one sets up a new palette every
	// time through the loop, based on a hue that changes every time.
	// The palette is a gradient from black, to a dark color based on the hue,
	// to a light color based on the hue, to white.
	//
	//   static uint8_t hue = 0;
	//   hue++;
	//   CRGB darkcolor  = CHSV(hue,255,192); // pure hue, three-quarters brightness
	//   CRGB lightcolor = CHSV(hue,128,255); // half 'whitened', full brightness
	//   gPal = CRGBPalette16( CRGB::Black, darkcolor, lightcolor, CRGB::White);



	if (frame == 100) {
		Fire2012WithPalette(); // run simulation frame, using palette colors
		frame = 0;
	}
	frame++;
}

int FireEffect::getHeat(int row, int col) {
	if (row < 0 || row > HEAT_ROW_NUM - 1 || col < 0 || col > HEAT_COL_NUM) {
		return 0;
	} else {
		return heat[row][col];
	}
}

void FireEffect::Fire2012WithPalette() {

	// Step 1.  Cool down every cell a little
	for (int row = 0; row < HEAT_ROW_NUM; row++) {
		for (int col = 0; col < HEAT_COL_NUM; col++) {
			heat[row][col] = qsub8(getHeat(row, col),
					random8(0, ((COOLING * 10) / CELL_NUM) + 2));
		}
	}

	// Step 2.  Heat from each cell drifts 'up' and diffuses a little
	for (int row = HEAT_ROW_NUM - 1; row >= 1; row--) {
		for (int col = 0; col < HEAT_COL_NUM; col++) {
			heat[row][col] = (getHeat(row - 1, col) + getHeat(row - 2, col)
					+ getHeat(row - 2, col)) / 3;
		}
	}

	/*	for (int k = NUM_LEDS - 1; k >= 2; k--) {
	 heat[k] = (heat[k - 1] + heat[k - 2] + heat[k - 2]) / 3;
	 }*/

	// Step 3.  Randomly ignite new 'sparks' of heat near the bottom
	if (random8() < SPARKING) {
		//int col = random8(HEAT_COL_NUM);
		int row = 0;
		for (int col = 0; col < HEAT_COL_NUM; col++) {
			heat[0][col] = qadd8(heat[row][col], random8(10, 50));
		}
	}

// map row #0

	uint16_t sum = 0;
	for (int col = 0; col < HEAT_COL_NUM; col++) {
		sum += heat[0][col];
	}
	sum /= HEAT_COL_NUM;
	ledBuffer[0] = map(sum);

	for (int row = 1; row < HEAT_ROW_NUM; row++) {
		for (int col = 0; col < HEAT_COL_NUM; col++) {
			ledBuffer[mapPixel(row, col)] = map(heat[row - 1][col]);
		}
	}
}

int FireEffect::mapPixel(int row, int col) {
	switch (row) {
	case 0:
		return 0;
		break;
	case 1:
		return 1 + col;
		break;
	case 2:
		return 11 + col;
		break;
	case 3:
		return 21 + col;
		break;
	}
	return 0;
}

CRGB FireEffect::map(uint8_t hotness) {
// Scale the heat value from 0-255 down to 0-240
// for best results with color palettes.
	byte colorindex = scale8(hotness, 240);
	CRGB color = ColorFromPalette(gPal, colorindex);
	return color;
}

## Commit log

2018-07-08 Eagle files for PCB Xara+Inkscape files for board layout BOM Gerber files for PCB manufacturing
    [Christmas_Star (Automatikusan mentett).csv, Christmas_Star.brd, Christmas_Star.csv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]
2018-07-08 Eagle+BOM+Gerbers Images of the schematics
    [Christmas_Star (Automatikusan mentett).csv, Christmas_Star.brd, Christmas_Star.csv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]

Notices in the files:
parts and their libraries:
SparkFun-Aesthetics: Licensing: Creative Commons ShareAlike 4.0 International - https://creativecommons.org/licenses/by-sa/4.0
